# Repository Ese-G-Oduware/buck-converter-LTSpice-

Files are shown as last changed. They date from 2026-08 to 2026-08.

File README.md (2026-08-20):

# 12V to 5V Step Down Buck Converter (LTSpice & KiCad PCB)
This is an asynchronous buck converter that steps down 12V to 5V, designed and simulates in LTSpice using the LTC4440 (IC) high-side gate driver with a bootstrap circuit.
| KiCad Schematic | LTSpice Schematic |
| :---: | :---: |
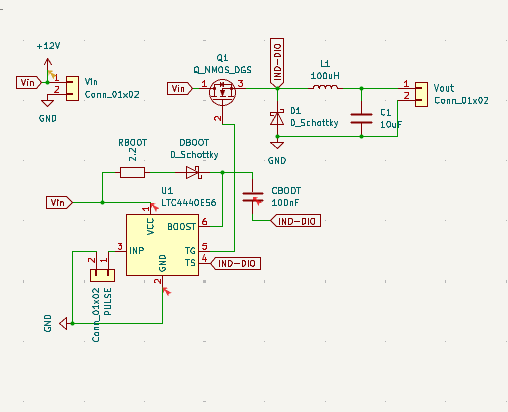
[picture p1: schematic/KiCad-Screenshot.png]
KiCad
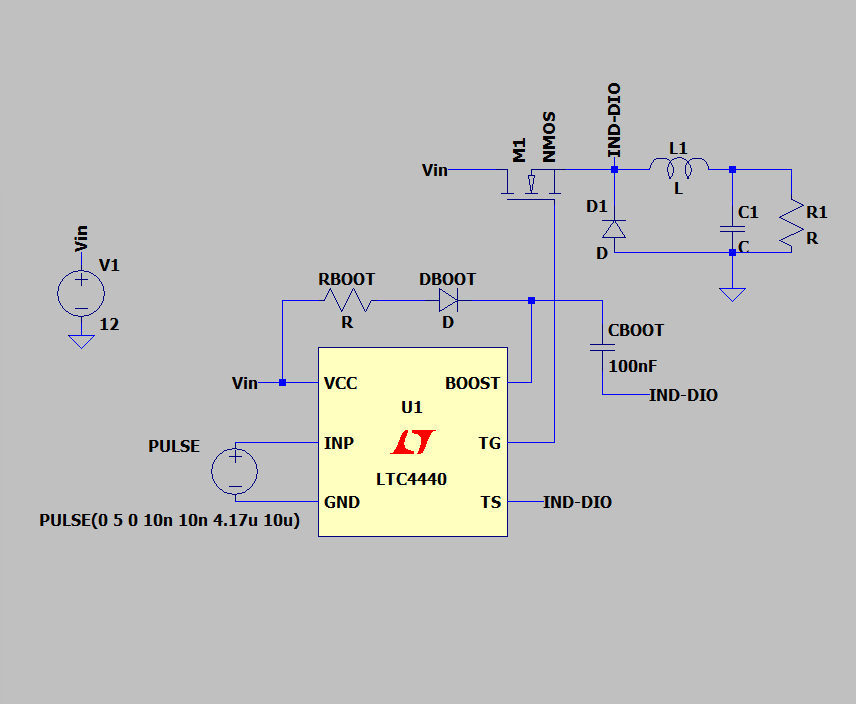
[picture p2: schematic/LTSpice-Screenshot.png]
LTSpice
|  |  |

## Key Specifications
* **Input Voltage ($V_{in}$):** 12V DC
* **Output Voltage ($V_{out}$):** ~4.8V DC (Steady-State)
* **Load Current ($I_{out}$):** 1A (5Ω Load)
* **Switching Frequency ($f_{sw}$):** 100 kHz (41.67% Duty Cycle)
* **Output Ripple ($\Delta V_{out}$):** ~39 mV (< 1%)
* **PCB Architecture:** 2-layer board optimized for high-frequency switching and low EMI

## Design Calculations
* **Duty Cycle:** $D = V_{out} / V_{in} = 5V / 12V = 41.67\%$
* **Inductor:** $L = \frac{(V_{in} - V_{out}) \cdot T_{on}}{\Delta I_L} = \frac{(12 - 5) \cdot 4.17\mu s}{0.3A} \approx 97.3\mu H \rightarrow 100\mu H$
* **High-Side MOSFET Drive:** Utilizes the LTC4440 high-speed driver paired with a bootstrap diode and capacitor ($C_{boot} = 100\text{nF}$) to elevate gate voltage above the floating switching node.

## Simulation & Results
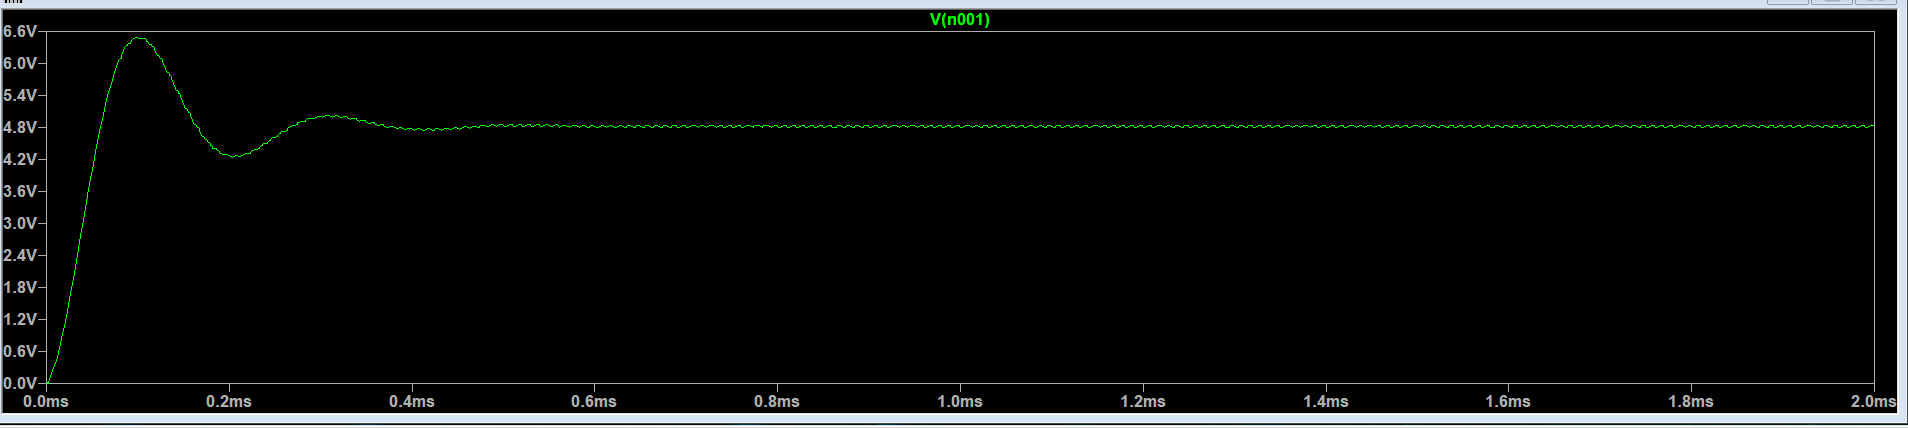
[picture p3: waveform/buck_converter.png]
Transient Waveform

* **Startup Phase:** Displays natural LC filter settling overshoot peaking at 6.5V.
* **Non-Idealities:** Steady-state output settles slightly below theoretical 5V at 4.8V due to MOSFET $R_

## PCB Layout & Manufacturing
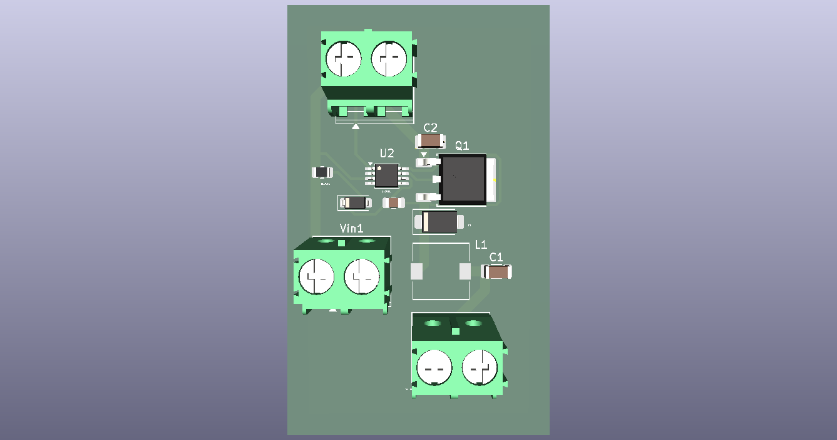
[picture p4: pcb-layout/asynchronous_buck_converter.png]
PCB Render

* **Compact Switching Loop:** Components positioned to minimize power loop area to reduce parasitic inductance and switching noise.
* **Thermal Management:** Integrated ground plane pours for efficient heat dissipation across components.
* **DRC Verification:** Passed full KiCad Design Rule Checks.

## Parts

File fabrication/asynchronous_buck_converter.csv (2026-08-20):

Id | Designator | Footprint | Quantity | Designation | Supplier and ref
1 | C1, C2 | C_1206_3216Metric | 2 | 10uF
2 | CBOOT1 | C_0805_2012Metric | 1 | 100nF
3 | D1 | D_SMA | 1 | D_Schottky
4 | DBOOT1 | D_SOD-123 | 1 | D_Schottky
5 | L1 | L_7.3x7.3_H3.5 | 1 | 100uH
6 | PULSE1, Vin1, Vout1 | TerminalBlock_Phoenix_PT-1,5-2-5.0-H_1x02_P5.00mm_Horizontal | 3 | Conn_01x02
7 | Q1 | TO-252-2 | 1 | Q_NMOS_DGS
8 | RBOOT1 | R_0805_2012Metric | 1 | 2.2
9 | U2 | MSOP-8-1EP_3x3mm_P0.65mm_EP1.68x1.88mm | 1 | LTC4440EMS8

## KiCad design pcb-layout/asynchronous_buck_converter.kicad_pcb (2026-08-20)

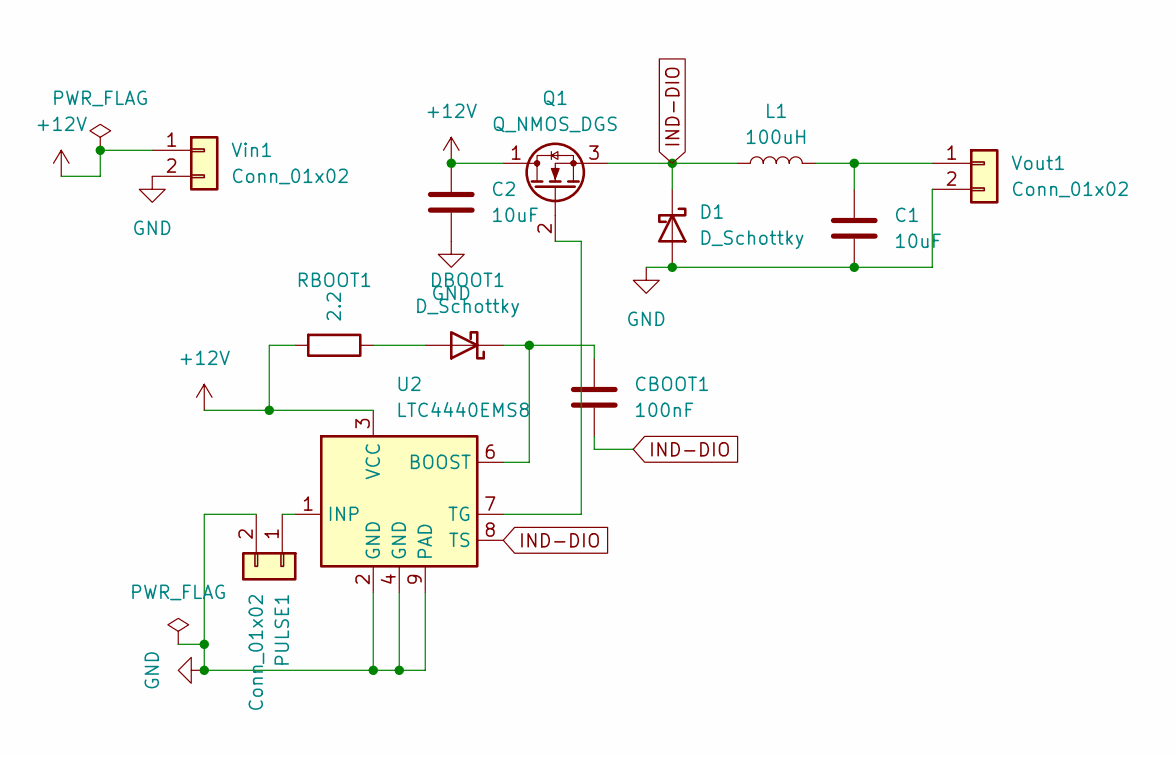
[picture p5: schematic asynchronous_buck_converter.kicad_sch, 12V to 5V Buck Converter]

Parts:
C1, C2: 10uF; C_1206_3216Metric
CBOOT1: 100nF; C_0805_2012Metric
D1: D_Schottky; D_SMA
DBOOT1: D_Schottky; D_SOD-123
L1: 100uH; L_7.3x7.3_H3.5
PULSE1: Conn_01x02; TerminalBlock_Phoenix_PT-1,5-2-5.0-H_1x02_P5.00mm_Horizontal
Q1: Q_NMOS_DGS; TO-252-2
RBOOT1: 2.2; R_0805_2012Metric
U2: LTC4440EMS8; MSOP-8-1EP_3x3mm_P0.65mm_EP1.68x1.88mm
Vin1: Conn_01x02; TerminalBlock_Phoenix_PT-1,5-2-5.0-H_1x02_P5.00mm_Horizontal
Vout1: Conn_01x02; TerminalBlock_Phoenix_PT-1,5-2-5.0-H_1x02_P5.00mm_Horizontal

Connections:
+12V: C2.1, Q1.1 (D), RBOOT1.2, U2.3 (VCC), Vin1.1
GND: C1.2, C2.2, D1.2 (A), PULSE1.2, U2.2 (GND), U2.4 (GND), U2.9 (PAD), Vin1.2, Vout1.2
IND-DIO: CBOOT1.2, D1.1 (K), L1.1, Q1.3 (S), U2.8 (TS)
unnamed: DBOOT1.2 (A), RBOOT1.1
unnamed: CBOOT1.1, DBOOT1.1 (K), U2.6 (BOOST)
unnamed: PULSE1.1, U2.1 (INP)
unnamed: Q1.2 (G), U2.7 (TG)
unnamed: C1.1, L1.2, Vout1.1

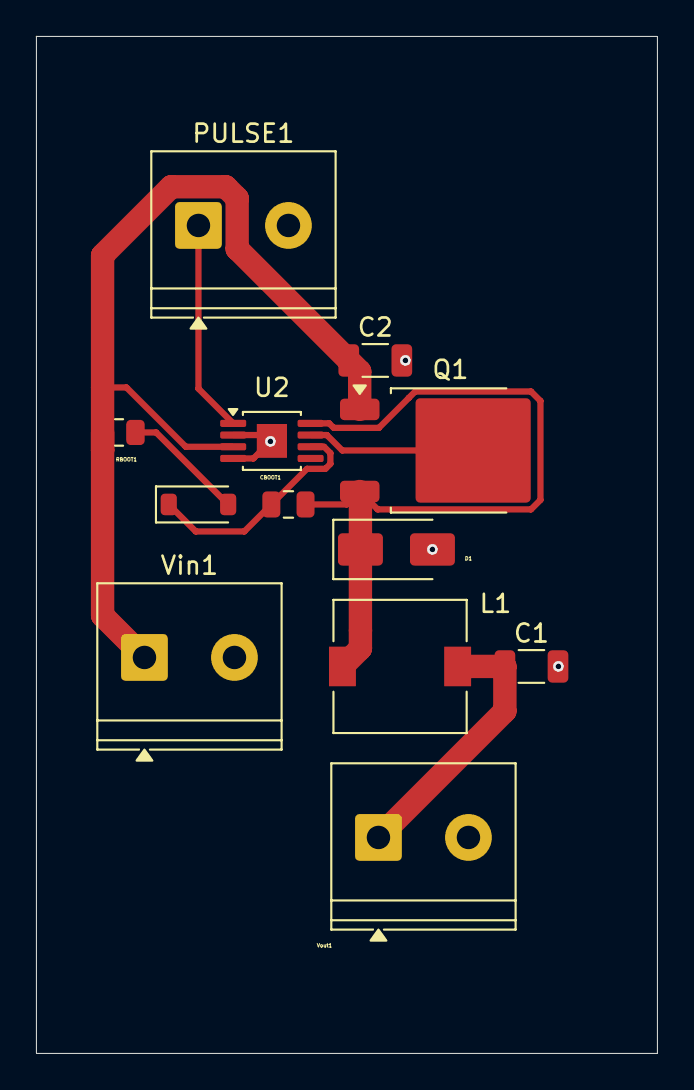
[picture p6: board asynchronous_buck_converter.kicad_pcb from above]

Board: 2 copper layers, 34.5 x 56.5 mm, 12 parts (0 on the bottom side), 8 nets.
